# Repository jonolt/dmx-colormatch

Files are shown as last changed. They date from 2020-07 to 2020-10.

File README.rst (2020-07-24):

DMX-Colormatch
==============

The purpose of this project is to match the colors of color LED fixtures from different manufacturers and output the corresponding dmx values for further use in light control panels.

Especially for low cost LED fixtures often no photometric data is available, which can be imported into professional lighting control consoles to generate exact colors. With small light control consoles this is not possible by design. Especially for low cost LED fixtures often no photometric data is available, which can be imported into professional lighting control consoles to generate exact colors. With small light control consoles this is not possible by design. This leads to the situation that colours have to be adjusted manually with a lot of patience, which is still possible in the HSV colour space (available on mid-range consoles) but is hardly possible in pure RGB or with pure DMX values even for an experienced lighting technician.

Firmaware
---------

Approach
^^^^^^^^

A simple rgbc color sensor is used to record the characteristics of a color setting which is then matched by an algorithm on another fixture by systematically varying DMX values. The system is designed to suppress systematic errors by e.g. differences between sensors (which do not need to be calibrated), the algorithm also eliminates influences from the measurement such as the integration time, which varies depending on the light intesistance.

The algorithm tries to minimize the following equation with n colors of the sensor and one clear value that can be the sum of the readings of all the sensors colors or the reading of a clear sensor:

.. math::
    x = \sum_{i=0}^n \left(\frac{cur_i}{cur_c}-\frac{ref_i}{ref_c}\right)^2\quad\text{with}\quad xxx_c=\sum_{i=0}^n xxx_i

Using relative values eleminates intesity, which would is a systemtical error when the intesity or measuring distance differs between reference and target fixture. With the given sensor with red(r), green(g), blue(b), clear(c) readings the equation is (writen out):

.. math::
    x = \left(\frac{cur_r}{cur_c}-\frac{ref_r}{ref_c}\right)^2+\left(\frac{cur_g}{cur_c}-\frac{ref_g}{ref_c}\right)^2+\left(\frac{cur_b}{cur_c}-\frac{ref_b}{ref_c}\right)^2

Algorithm
^^^^^^^^^

Since no intesity is left, one dmx channel has to be made a reference channel and has to be constant. The most robust aproach is to make a match with each channel being at a given level (mostly 255) and variying the other. The run with the smallest x value is then the best solution.

The Algorithm itself is then quite simple:
  Flowchart is in work

Hardware
--------

work in progress

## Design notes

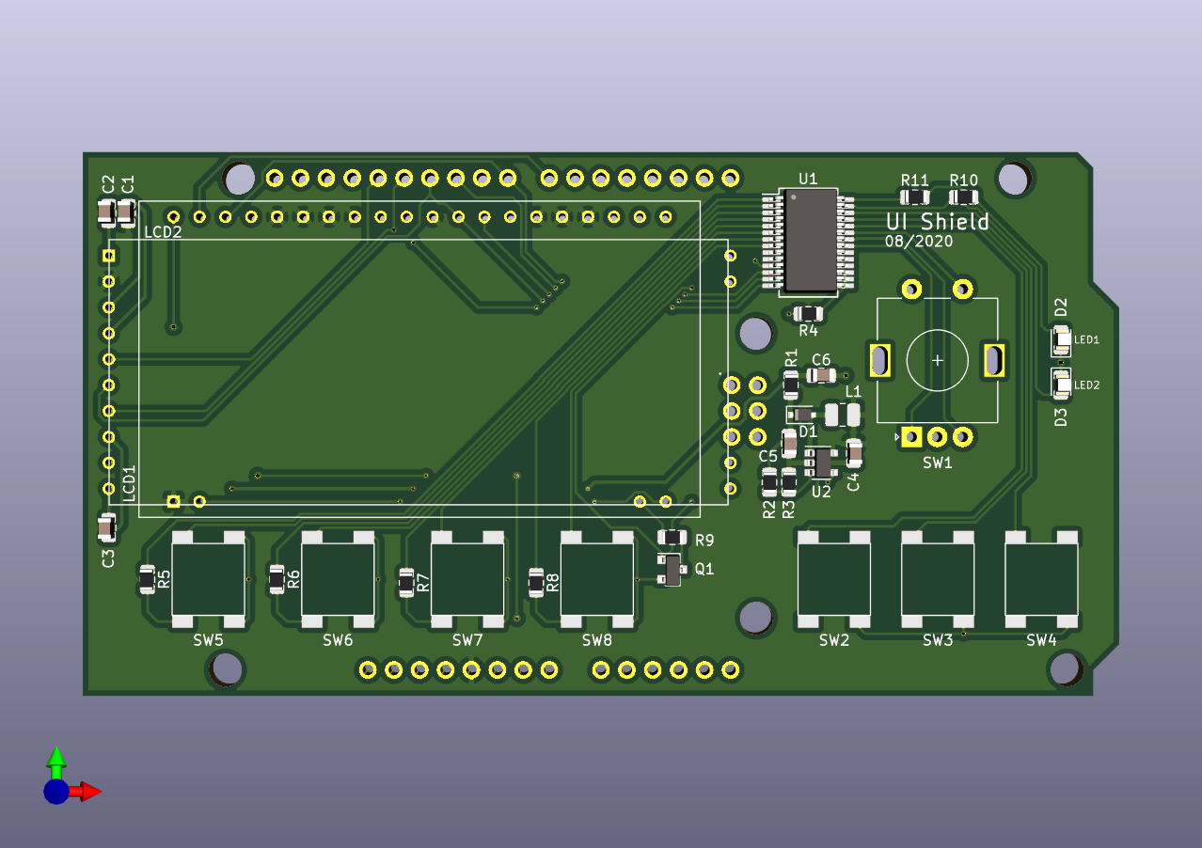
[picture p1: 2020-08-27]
board_kicad/UI-Shield/board_F.png

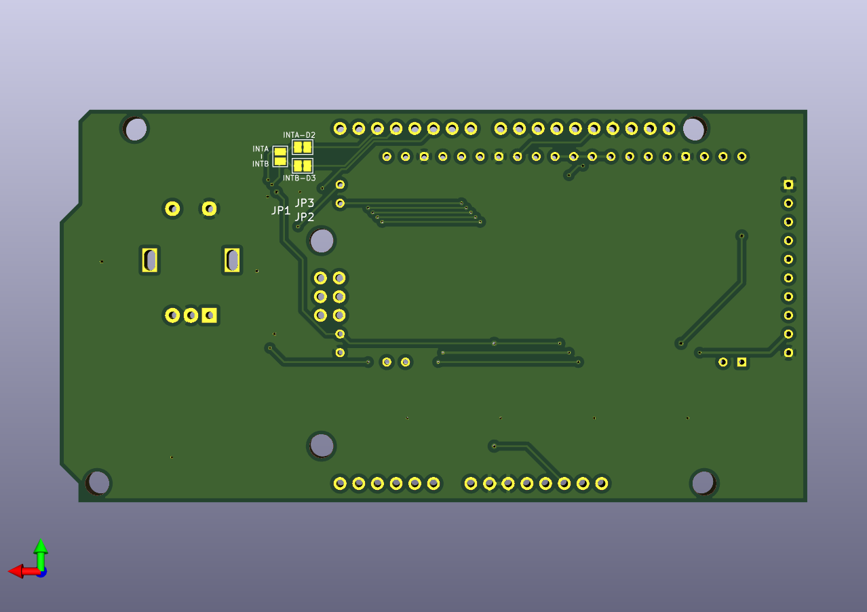
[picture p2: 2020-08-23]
board_kicad/UI-Shield/board_B.png

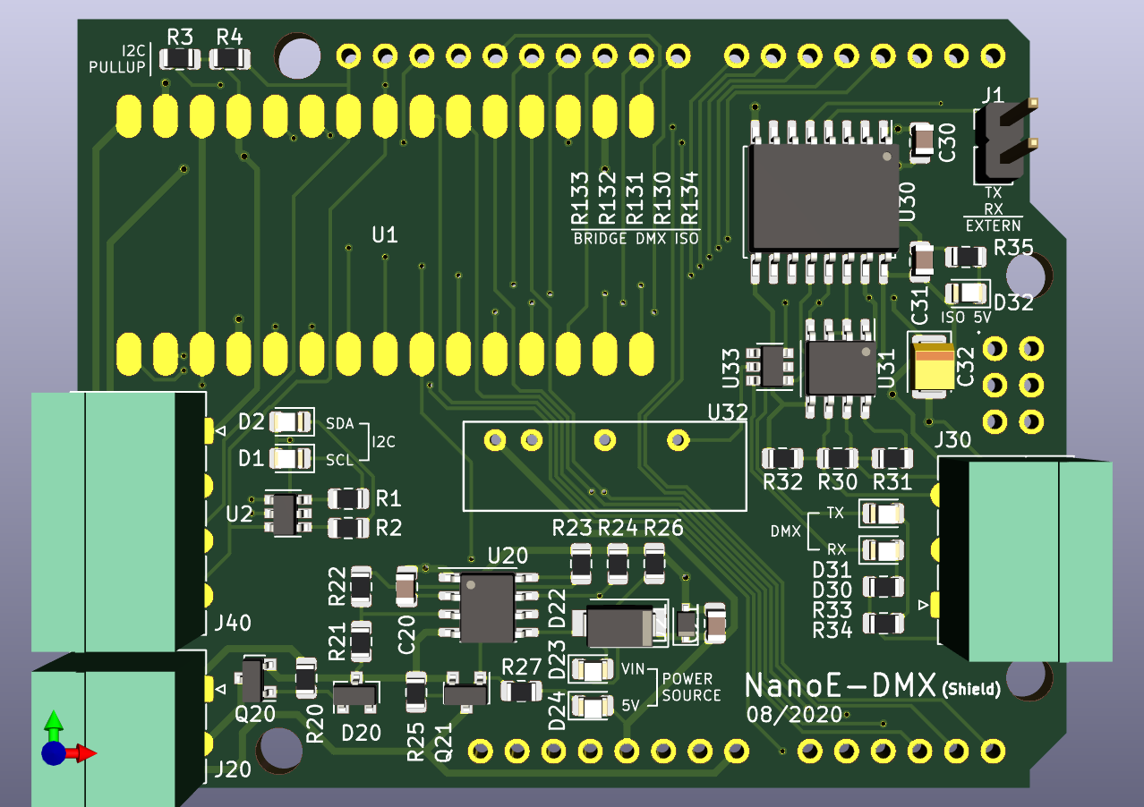
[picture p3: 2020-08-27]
board_kicad/NanoE-DMX/board_F.png

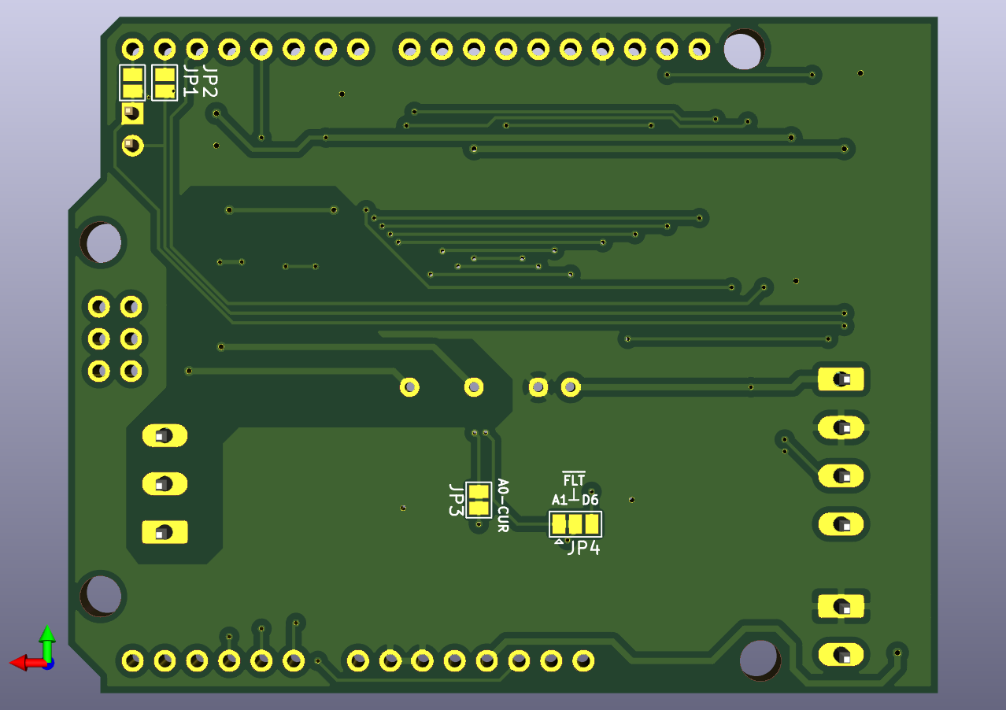
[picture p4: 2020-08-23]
board_kicad/NanoE-DMX/board_B.png

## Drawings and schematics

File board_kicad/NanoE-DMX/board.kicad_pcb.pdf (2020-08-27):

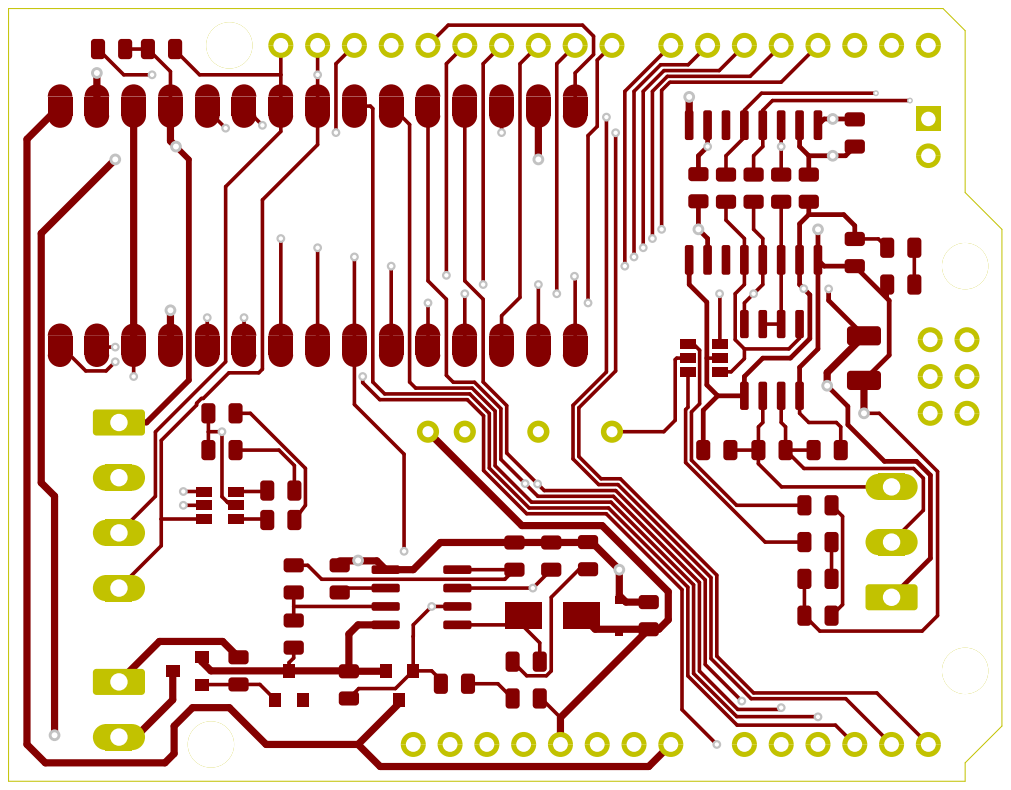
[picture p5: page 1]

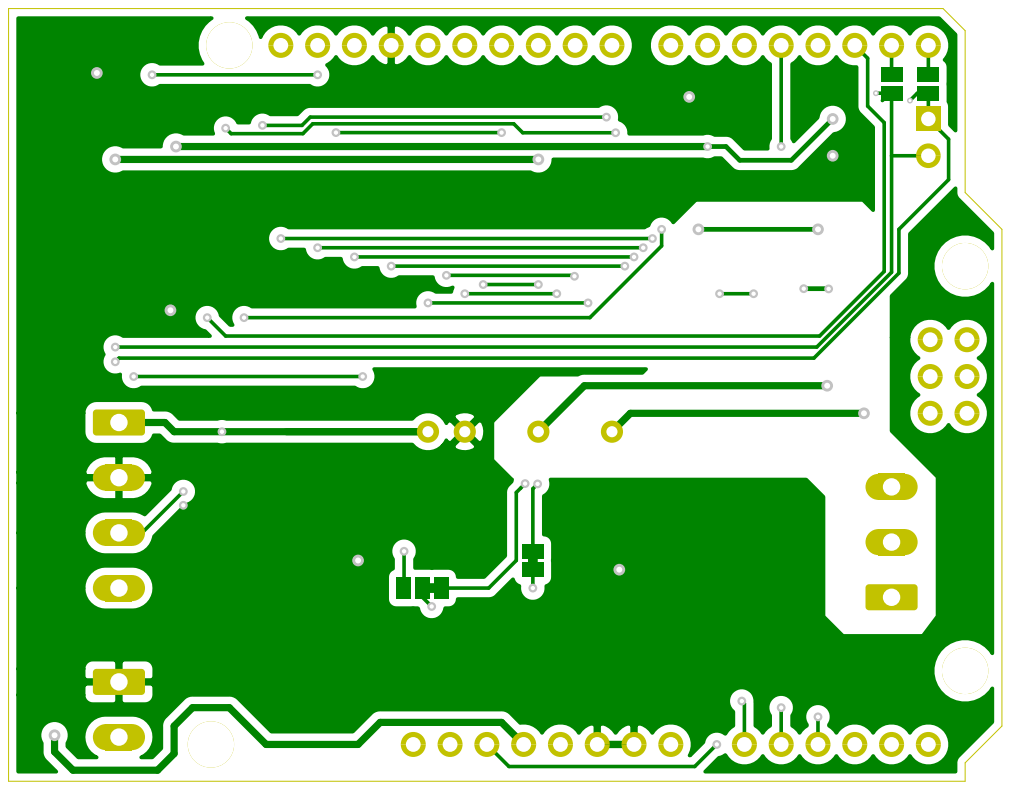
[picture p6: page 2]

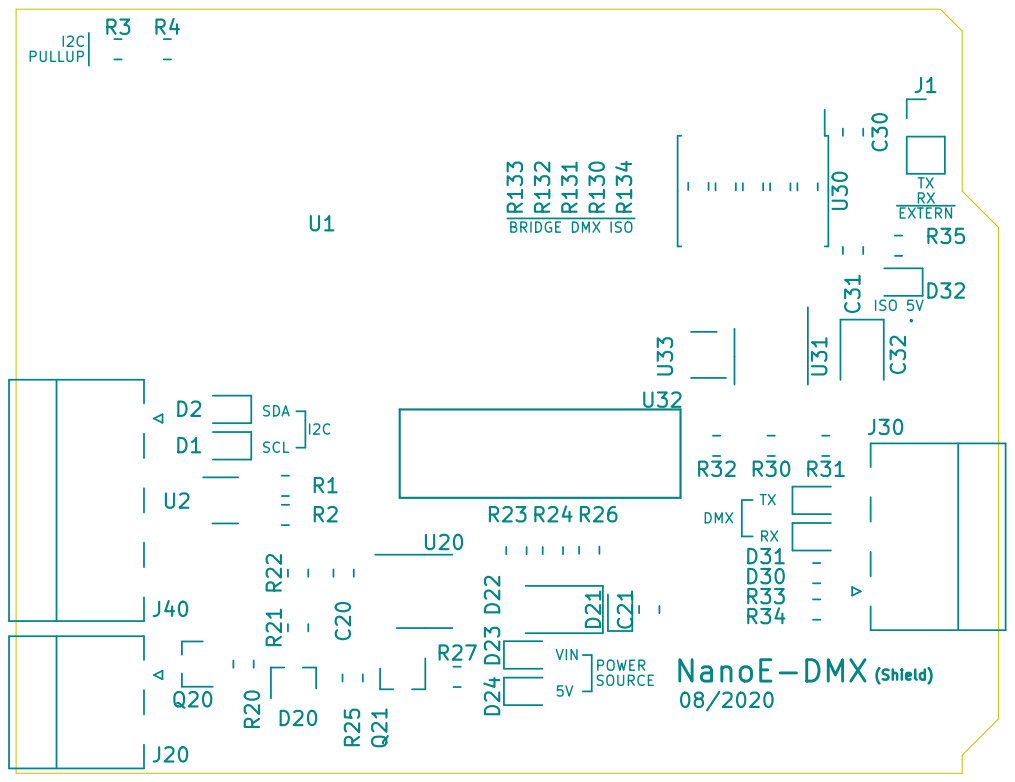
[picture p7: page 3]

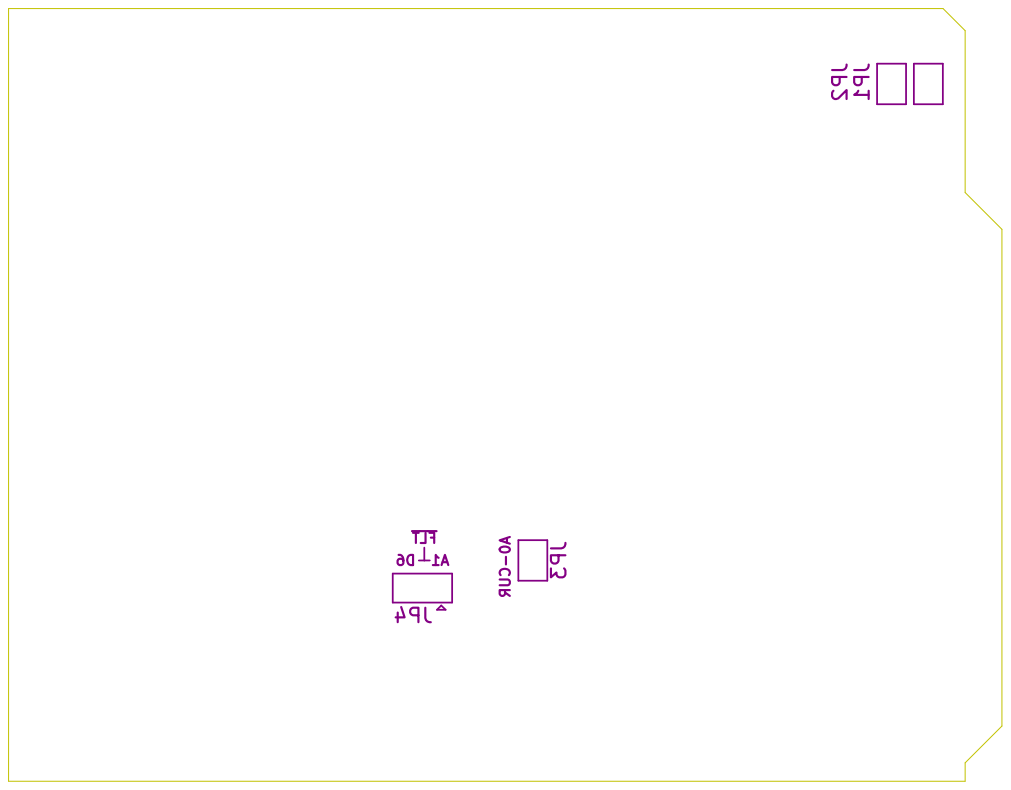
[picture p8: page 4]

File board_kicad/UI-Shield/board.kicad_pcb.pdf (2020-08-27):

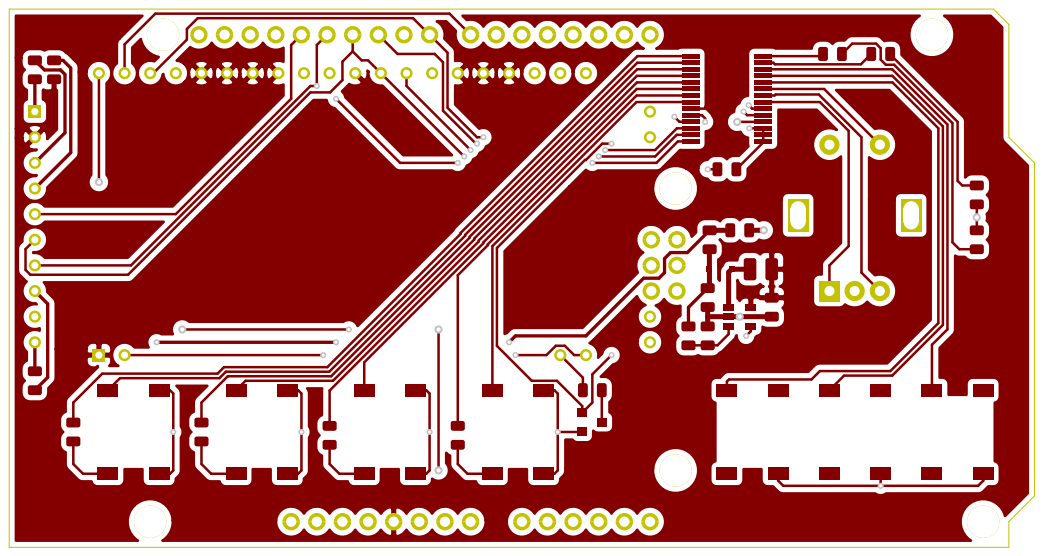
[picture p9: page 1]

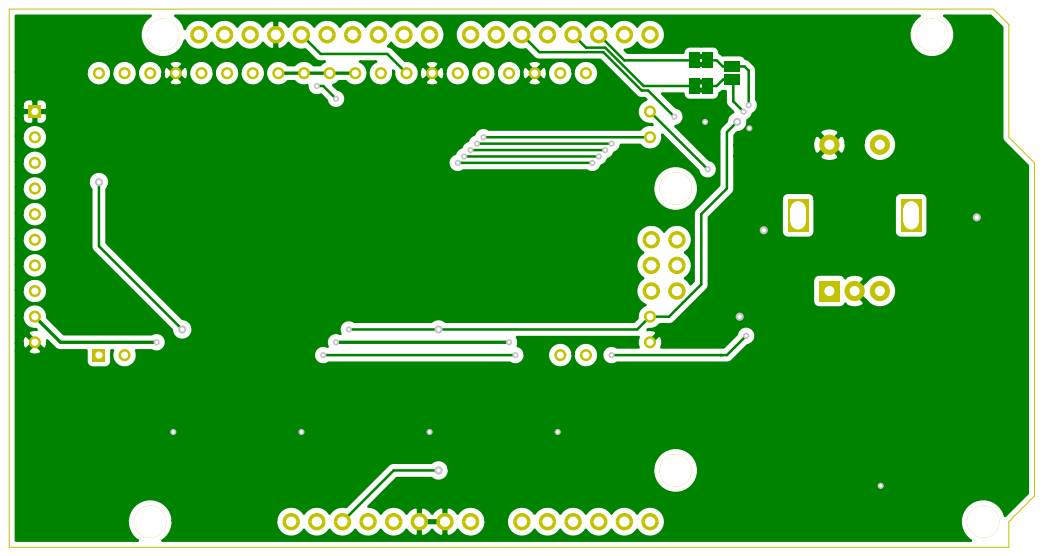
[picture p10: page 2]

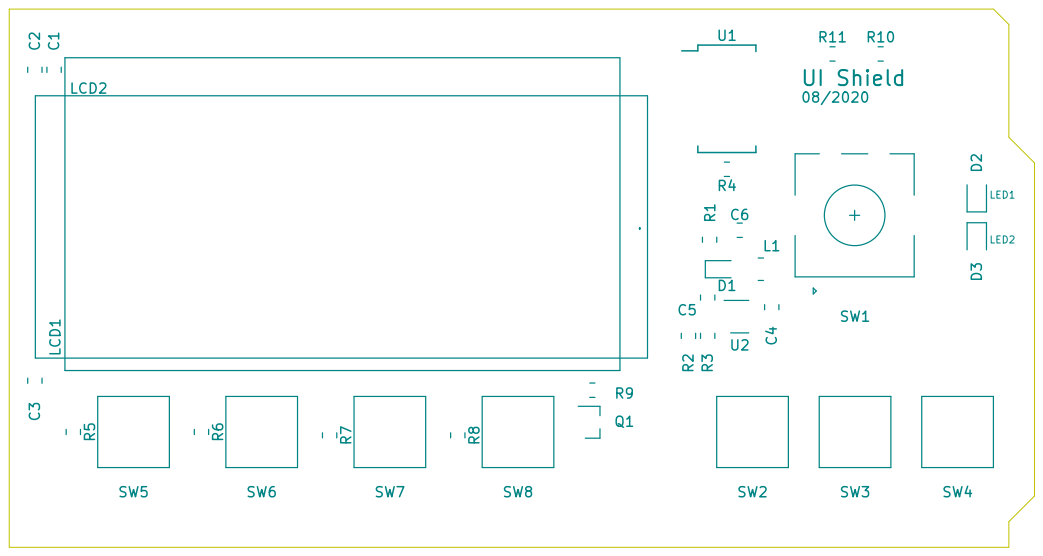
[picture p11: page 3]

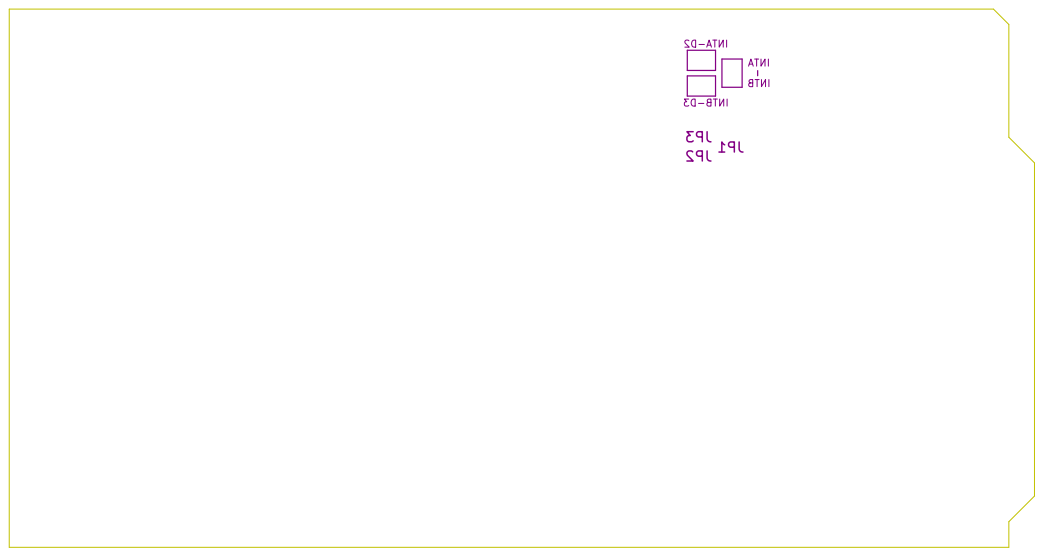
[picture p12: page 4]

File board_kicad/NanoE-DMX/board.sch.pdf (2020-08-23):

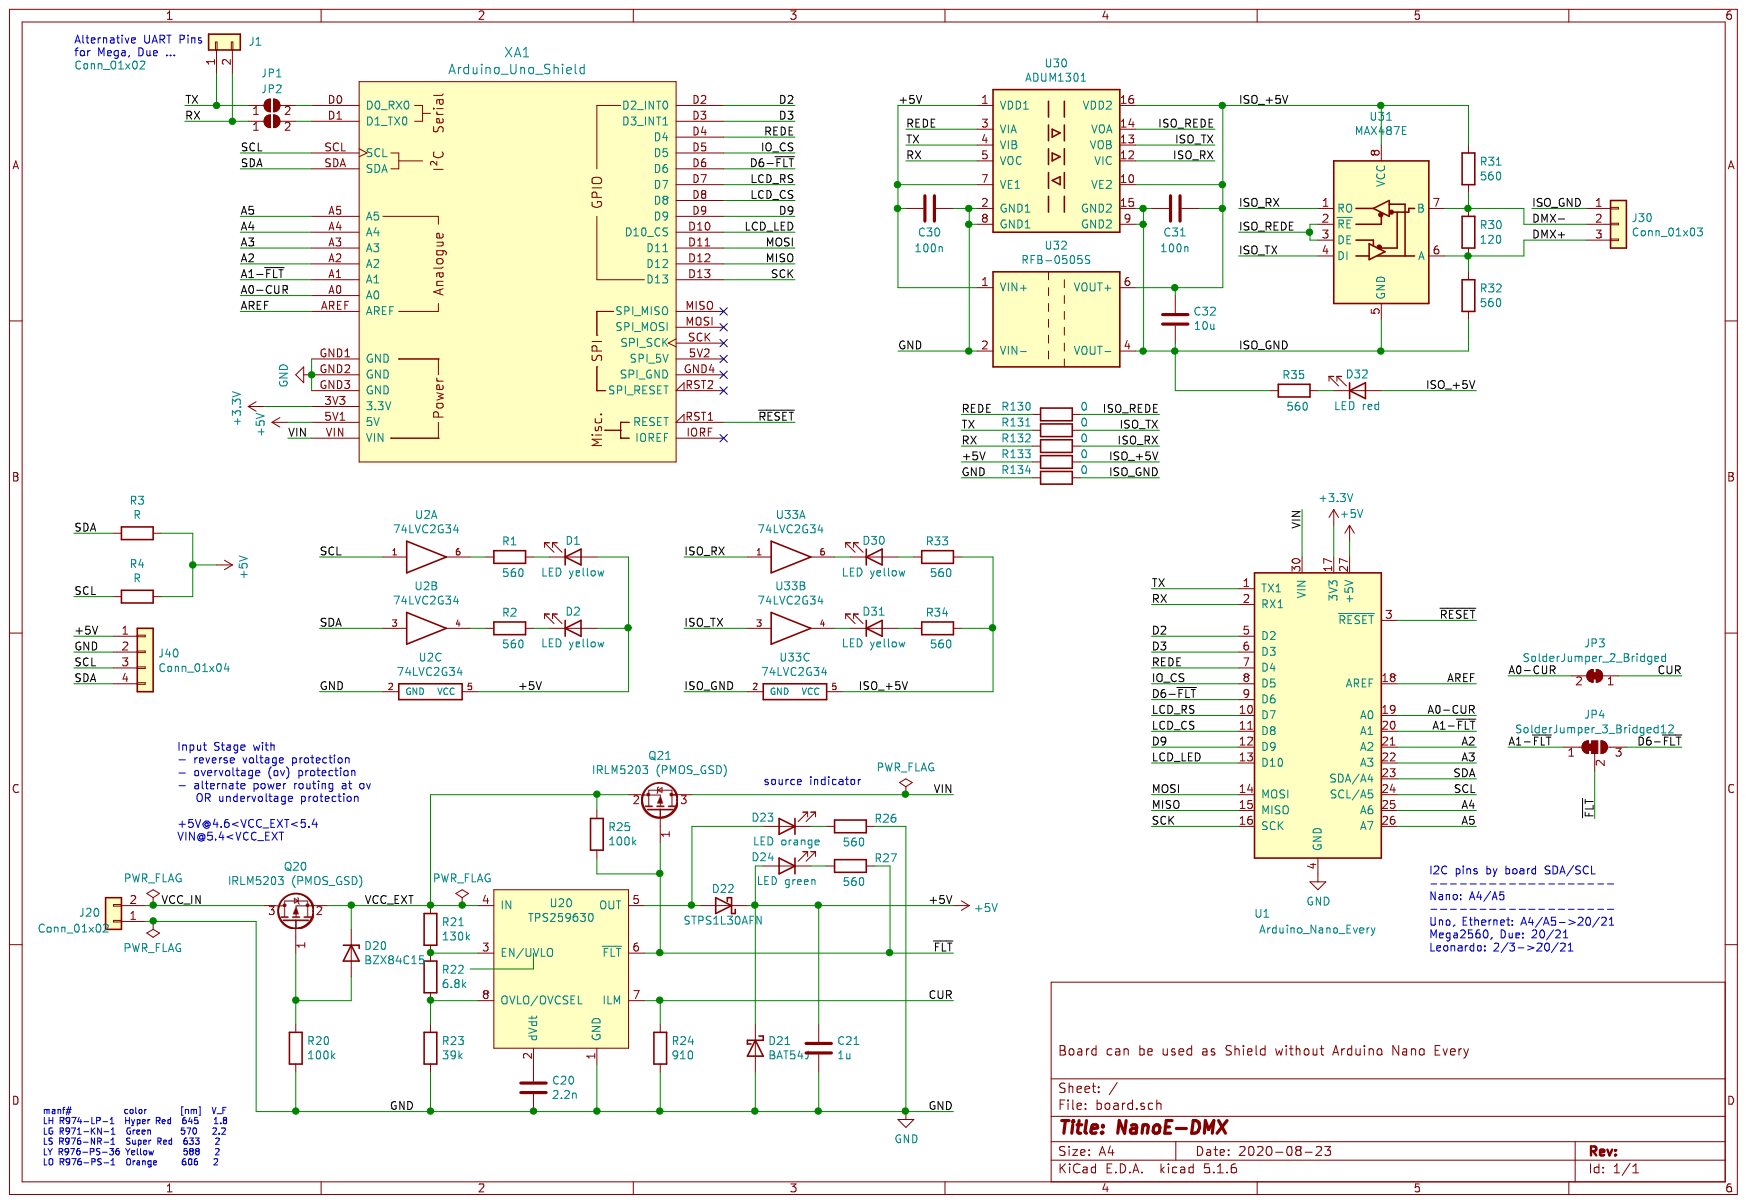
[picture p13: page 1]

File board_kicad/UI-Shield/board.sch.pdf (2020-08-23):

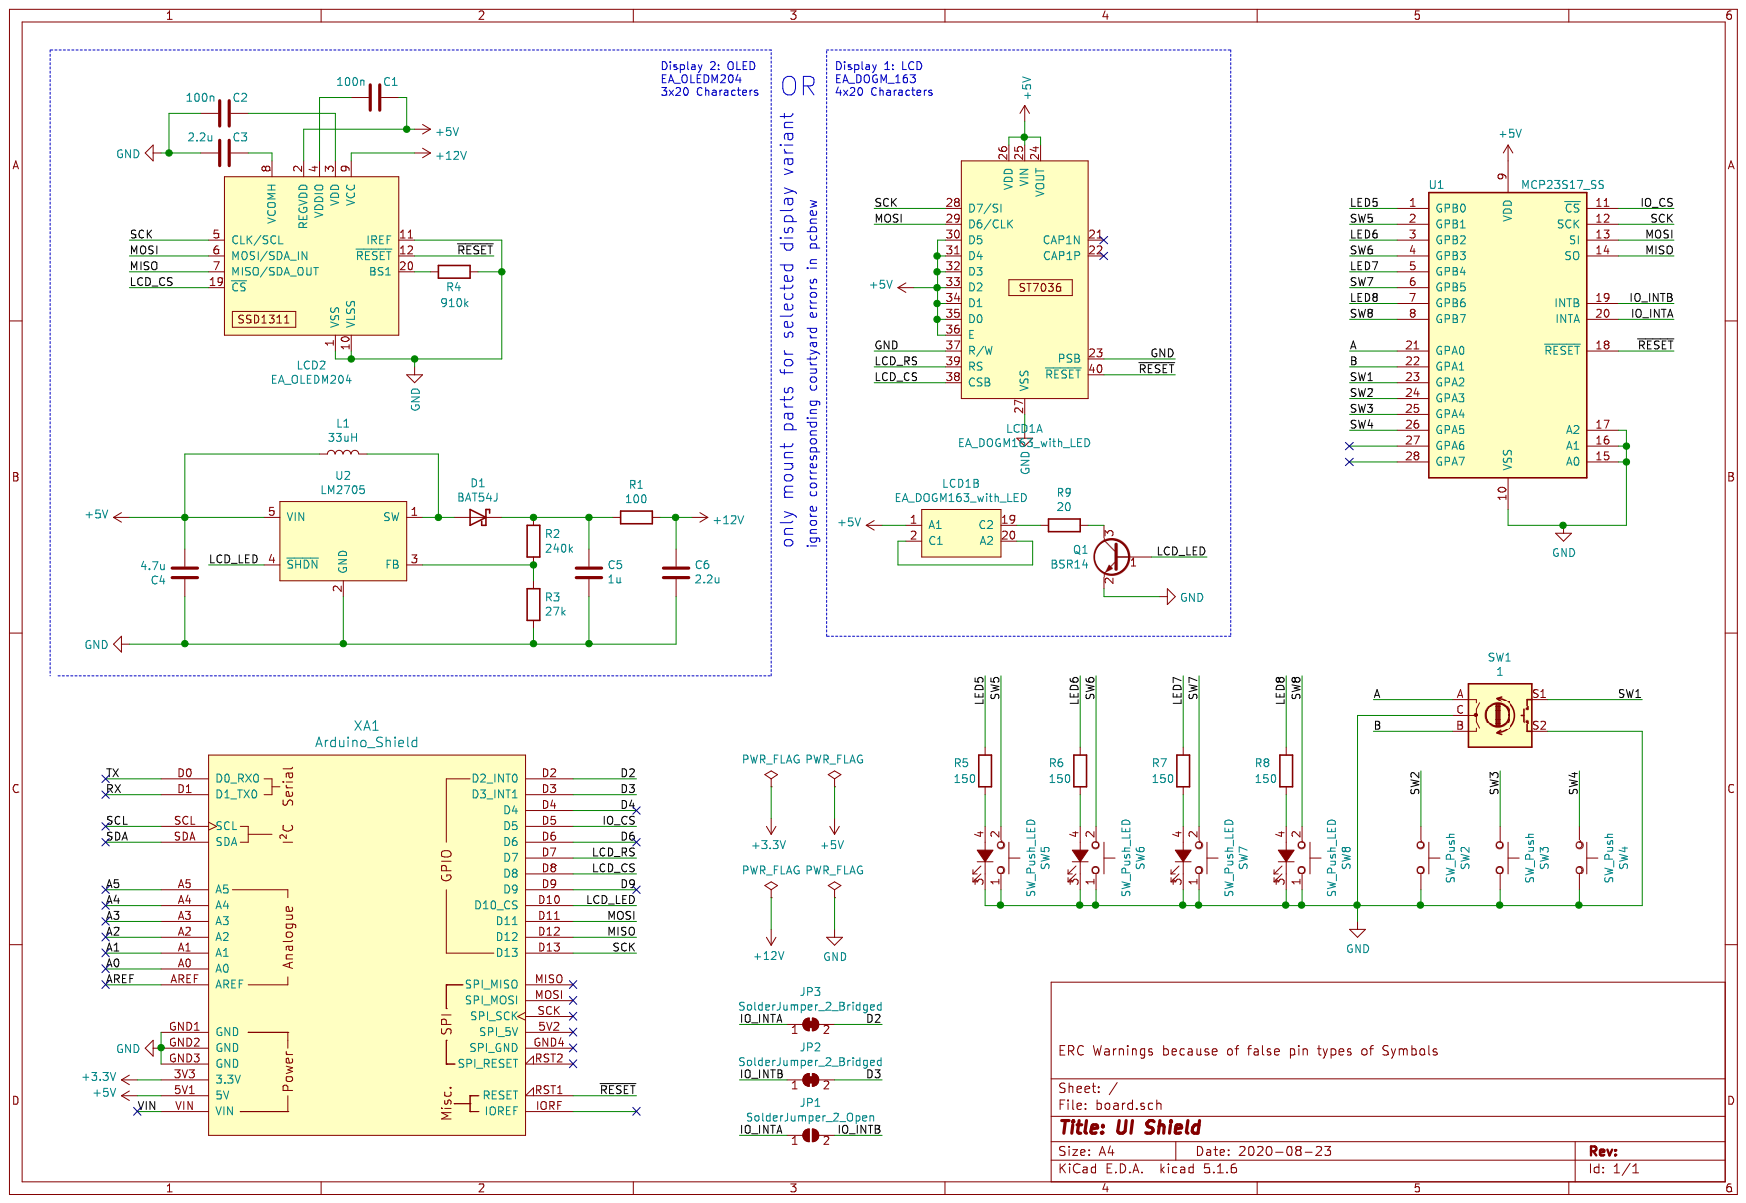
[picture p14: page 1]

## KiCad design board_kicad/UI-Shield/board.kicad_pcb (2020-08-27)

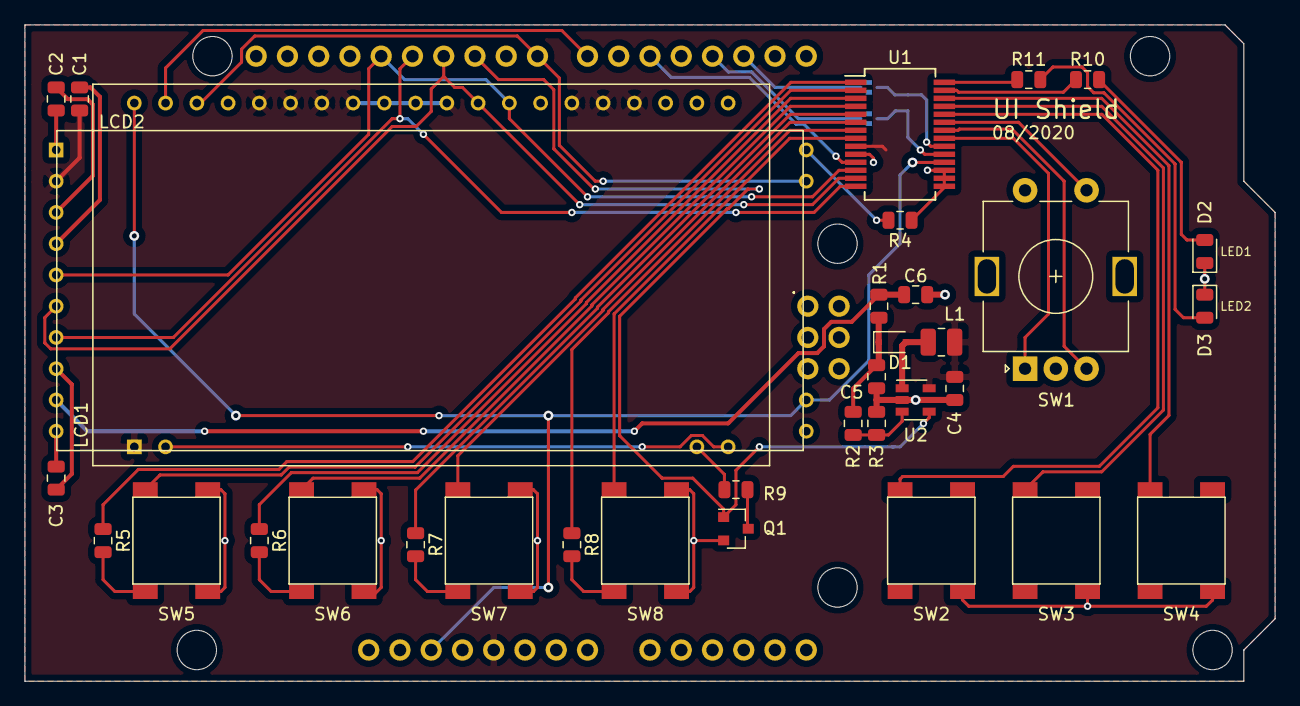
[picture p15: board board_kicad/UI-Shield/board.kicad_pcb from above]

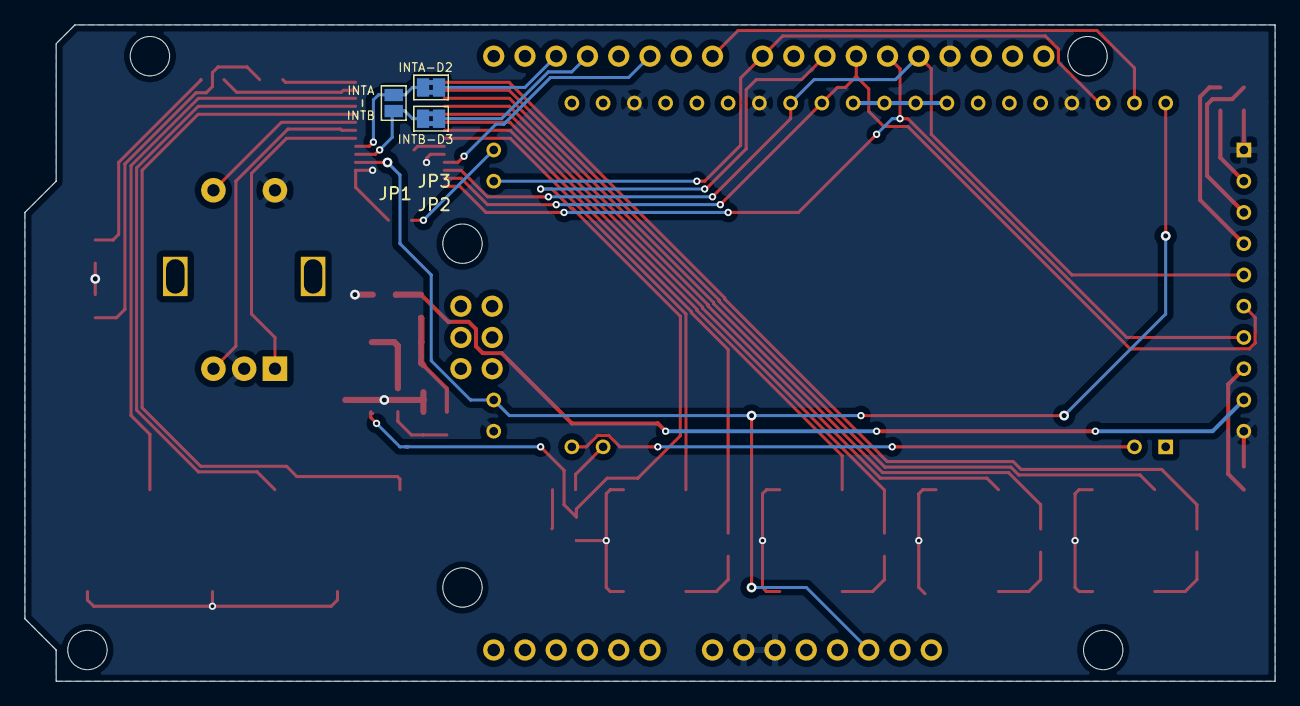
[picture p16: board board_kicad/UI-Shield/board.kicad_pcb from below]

Board: 2 copper layers, 101.6 x 53.3 mm, 38 parts (3 on the bottom side), 47 nets.

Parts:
C1, C2: 100n; C_0805_2012Metric
C3, C6: 2.2u; C_0805_2012Metric
C4: 4.7u; C_0805_2012Metric
C5: 1u; C_0805_2012Metric
D1: BAT54J; D_SOD-323F
D2, D3: LED; LED_0805_2012Metric
JP1: SolderJumper_2_Open; SolderJumper-2_P1.3mm_Open_Pad1.0x1.5mm
JP2, JP3: SolderJumper_2_Bridged; SolderJumper-2_P1.3mm_Bridged2Bar_Pad1.0x1.5mm
L1: 33uH; L_1008_2520Metric
LCD1: EA_DOGM163_with_LED; DOGM162_with_LED
LCD2: EA_OLEDM204; OLEDM204_6GGA
Q1: BSR14; SOT-23
R1: 100; R_0805_2012Metric
R2: 240k; R_0805_2012Metric
R3: 27k; R_0805_2012Metric
R4: 910k; R_0805_2012Metric
R5, R6, R7, R8: 150; R_0805_2012Metric
R9: 20; R_0805_2012Metric
R10, R11: 560; R_0805_2012Metric
SW1: 1; RotaryEncoder_Alps_EC11E-Switch_Vertical_H20mm
SW2, SW3, SW4: SW_Push; Marquardt_3006_Series
SW5, SW6, SW7, SW8: SW_Push_LED; Marquardt_3006_Series
U1: MCP23S17_SS; SSOP-28_5.3x10.2mm_P0.65mm
U2: LM2705; SOT-23-5
XA1: Arduino_Shield; Arduino_Shield_Large

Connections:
+5V: C1.1, C4.1, L1.1, LCD1.1, LCD1.24, LCD1.25, LCD1.26, LCD1.30, LCD1.31, LCD1.32, LCD1.33, LCD1.34, LCD1.35, LCD1.36, LCD2.2, U1.9, U2.5, XA1.5V1
+12V: C6.2, LCD2.9, R1.1
/A: SW1.A, U1.21
/B: SW1.B, U1.22
/D2: JP3.2, XA1.D2
/D3: JP2.2, XA1.D3
/IO_CS: U1.11, XA1.D5
/IO_INTA: JP1.1, JP3.1, U1.20
/IO_INTB: JP1.2, JP2.1, U1.19
/LCD_CS: LCD1.38, LCD2.19, XA1.D8
/LCD_LED: Q1.1, U2.4, XA1.D10
/LCD_RS: LCD1.39, XA1.D7
/LED1: R10.1, U1.27
/LED2: R11.1, U1.28
/LED5: R5.1, U1.1
/LED6: R6.1, U1.3
/LED7: R7.1, U1.5
/LED8: R8.1, U1.7
/MISO: LCD2.7, U1.14, XA1.D12
/MOSI: LCD1.29, LCD2.6, U1.13, XA1.D11
/SCK: LCD1.28, LCD2.5, U1.12, XA1.D13
/SW1: SW1.S1, U1.23
/SW2: SW2.2, U1.24
/SW3: SW3.2, U1.25
/SW4: SW4.2, U1.26
/SW5: SW5.2, U1.2
/SW6: SW6.2, U1.4
/SW7: SW7.2, U1.6
/SW8: SW8.2, U1.8
/~RESET: LCD1.40, LCD2.12, U1.18, XA1.RST1
GND: C2.2, C3.2, C4.2, C5.1, C6.1, D2.1, D3.1, LCD1.23, LCD1.27, LCD1.37, LCD2.1, LCD2.10, LCD2.11, Q1.2, R3.2, R4.1, SW1.C, SW1.S2, SW2.1, SW3.1, SW4.1, SW5.1, SW5.3, SW6.1, SW6.3, SW7.1, SW7.3, SW8.1, SW8.3, U1.10, U1.15, U1.16, U1.17, U2.2, XA1.GND1, XA1.GND2, XA1.GND3
unnamed: C1.2, LCD2.4
unnamed: C2.1, LCD2.3
unnamed: C3.1, LCD2.8
unnamed: C5.2, D1.1, R1.2, R2.1
unnamed: D1.2, L1.2, U2.1
unnamed: D2.2, R10.2
unnamed: D3.2, R11.2
unnamed: LCD1.2, LCD1.20
unnamed: LCD1.19, R9.2
unnamed: LCD2.20, R4.2
unnamed: Q1.3, R9.1
unnamed: R2.2, R3.1, U2.3
unnamed: R5.2, SW5.4
unnamed: R6.2, SW6.4
unnamed: R7.2, SW7.4
unnamed: R8.2, SW8.4

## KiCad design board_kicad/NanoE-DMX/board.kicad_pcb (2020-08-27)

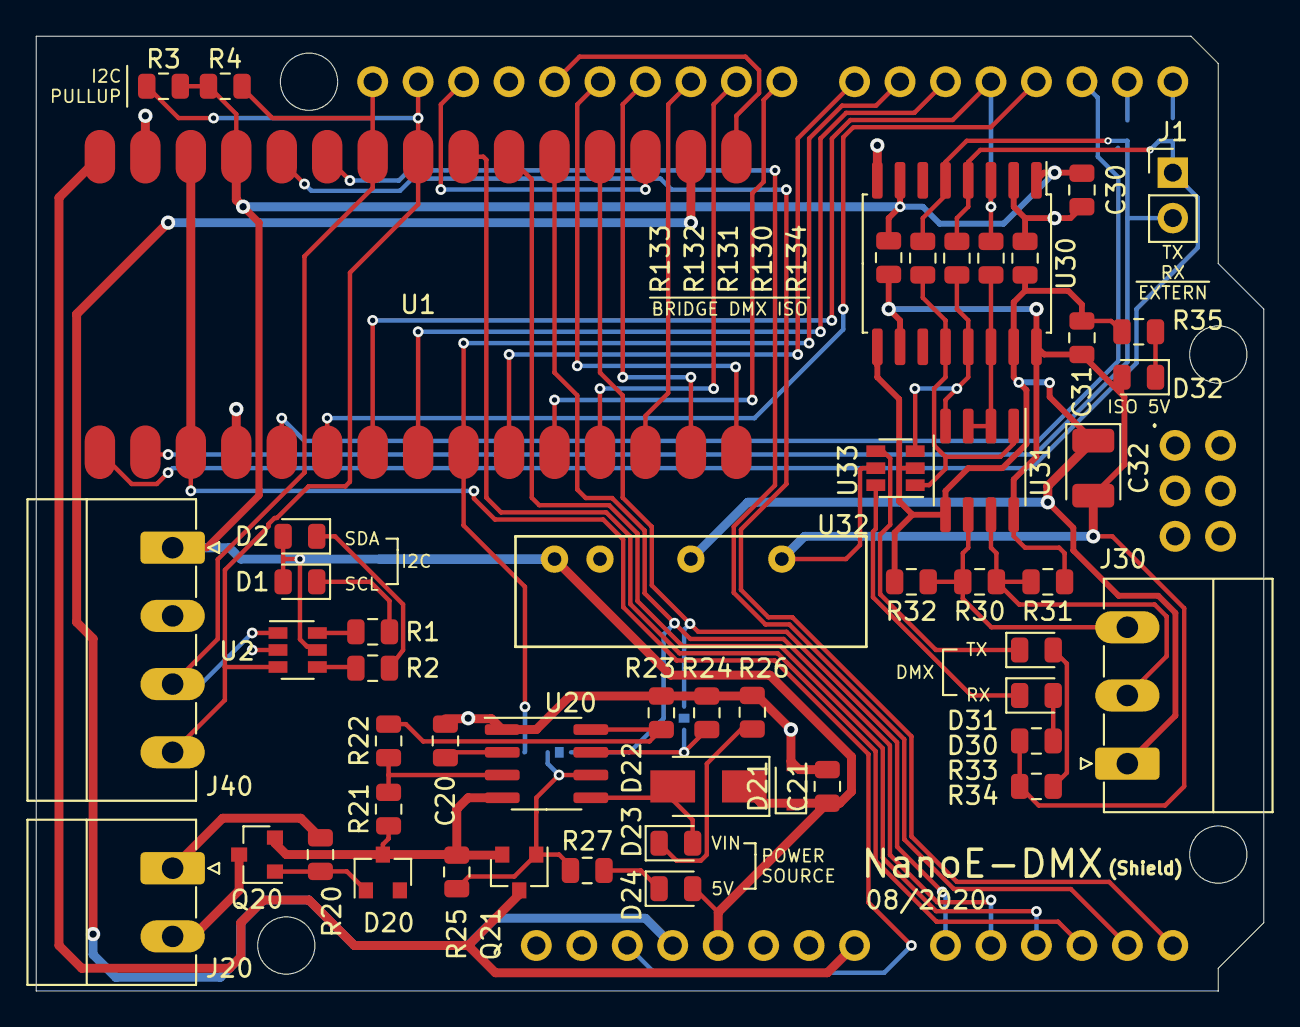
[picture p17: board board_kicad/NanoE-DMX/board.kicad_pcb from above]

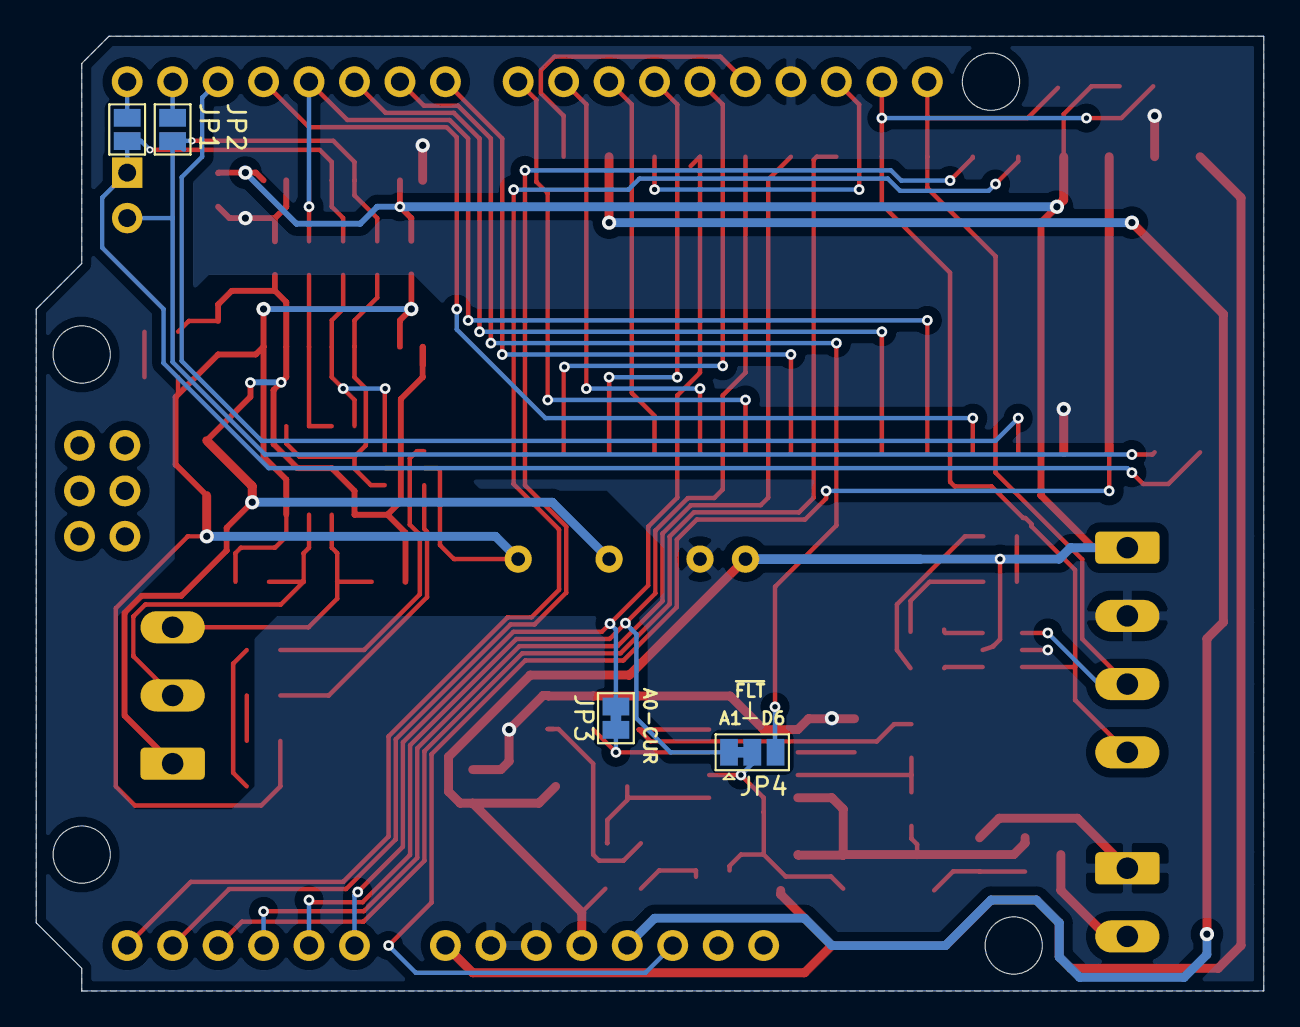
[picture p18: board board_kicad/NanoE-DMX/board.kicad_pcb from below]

Board: 2 copper layers, 68.6 x 53.3 mm, 56 parts (4 on the bottom side), 57 nets.

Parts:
C20: 2.2n; C_0805_2012Metric
C21: 1u; C_0805_2012Metric
C30, C31: 100n; C_0805_2012Metric
C32: 10u; CP_EIA-3528-15_AVX-H
D1, D2, D30, D31: LED yellow; LED_0805_2012Metric
D20: BZX84C15; D_SOT-23_ANK
D21: BAT54J; D_SOD-323F
D22: STPS1L30AFN; D_SMA
D23: LED orange; LED_0805_2012Metric
D24: LED green; LED_0805_2012Metric
D32: LED red; LED_0805_2012Metric
J1: Conn_01x02; PinHeader_1x02_P2.54mm_Vertical
J20: Conn_01x02; PhoenixContact_MC_1,5_2-G-3.81_1x02_P3.81mm_Horizontal
J30: Conn_01x03; PhoenixContact_MC_1,5_3-G-3.81_1x03_P3.81mm_Horizontal
J40: Conn_01x04; PhoenixContact_MC_1,5_4-G-3.81_1x04_P3.81mm_Horizontal
JP1, JP2: SolderJumper_2_Open; SolderJumper-2_P1.3mm_Open_Pad1.0x1.5mm
JP3: SolderJumper_2_Bridged; SolderJumper-2_P1.3mm_Bridged_Pad1.0x1.5mm
JP4: SolderJumper_3_Bridged12; SolderJumper-3_P1.3mm_Bridged12_Pad1.0x1.5mm
Q20, Q21: IRLM5203 (PMOS_GSD); SOT-23
R1, R2, R26, R27, R31, R32, R33, R34, R35: 560; R_0805_2012Metric
R3, R4: R; R_0805_2012Metric
R20, R25: 100k; R_0805_2012Metric
R21: 130k; R_0805_2012Metric
R22: 6.8k; R_0805_2012Metric
R23: 39k; R_0805_2012Metric
R24: 910; R_0805_2012Metric
R30: 120; R_0805_2012Metric
R130, R131, R132, R133, R134: 0; R_0805_2012Metric
U1: Arduino_Nano_Every; Nano_Every_SMD
U2, U33: 74LVC2G34; SOT-23-6
U20: TPS259630; SOIC-8_3.9x4.9mm_P1.27mm
U30: ADUM1301; SOIC-16W_7.5x10.3mm_P1.27mm
U31: MAX487E; SOIC-8_3.9x4.9mm_P1.27mm
U32: RFB-0505S; SIP7-1-2-4-6
XA1: Arduino_Uno_Shield; Arduino_Shield

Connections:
+3V3: U1.17, XA1.3V3
+5V: C21.1, C30.2, D1.2, D2.2, D21.1, D22.1, D24.2, J40.1, R3.1, R4.1, R133.2, U1.27, U2.5, U30.1, U30.7, U32.1, XA1.5V1
/A0-CUR: JP3.2, U1.19, XA1.A0
/A1-~FLT: JP4.1, U1.20, XA1.A1
/A2: U1.21, XA1.A2
/A3: U1.22, XA1.A3
/A4: U1.25, XA1.A4
/A5: U1.26, XA1.A5
/AREF: U1.18, XA1.AREF
/CUR: JP3.1, R24.1, U20.7
/D2: U1.5, XA1.D2
/D3: U1.6, XA1.D3
/D6-~FLT: JP4.3, U1.9, XA1.D6
/D9: U1.12, XA1.D9
/DMX+: J30.3, R30.2, R32.1, U31.6
/DMX-: J30.2, R30.1, R31.2, U31.7
/IO_CS: U1.8, XA1.D5
/ISO_+5V: C31.1, C32.2, D32.2, R31.1, R33.1, R34.1, R133.1, U30.10, U30.16, U31.8, U32.6, U33.5
/ISO_GND: C31.2, C32.1, J30.1, R32.2, R35.2, R134.1, U30.9, U30.15, U31.5, U32.4, U33.2
/ISO_REDE: R130.1, U30.14, U31.2, U31.3
/ISO_RX: R132.1, U30.12, U31.1, U33.1
/ISO_TX: R131.1, U30.13, U31.4, U33.3
/LCD_CS: U1.11, XA1.D8
/LCD_LED: U1.13, XA1.D10
/LCD_RS: U1.10, XA1.D7
/MISO: U1.15, XA1.D12
/MOSI: U1.14, XA1.D11
/REDE: R130.2, U1.7, U30.3, XA1.D4
/RX: J1.2, JP2.1, R132.2, U1.2, U30.5
/SCK: U1.16, XA1.D13
/SCL: J40.3, R4.2, U1.24, U2.1, XA1.SCL
/SDA: J40.4, R3.2, U1.23, U2.3, XA1.SDA
/TX: J1.1, JP1.1, R131.2, U1.1, U30.4
/VCC_EXT: D20.1, Q20.2, Q21.2, R21.1, R25.1, U20.4
/VCC_IN: J20.2, Q20.3
/VIN: Q21.3, U1.30, XA1.VIN
/~FLT: JP4.2, Q21.1, R25.2, R27.1, U20.6
/~RESET: U1.3, U1.28, XA1.RST1
GND: C20.2, C21.2, C30.1, D21.2, J20.1, J40.2, R20.2, R23.2, R24.2, R26.1, R134.2, U1.4, U1.29, U2.2, U20.1, U30.2, U30.8, U32.2, XA1.GND1, XA1.GND2, XA1.GND3
unnamed: C20.1, U20.2
unnamed: D1.1, R1.1
unnamed: D2.1, R2.1
unnamed: D20.2, Q20.1, R20.1
unnamed: D22.2, D23.2, U20.5
unnamed: D23.1, R26.2
unnamed: D24.1, R27.2
unnamed: D30.1, U33.6
unnamed: D30.2, R33.2
unnamed: D31.1, U33.4
unnamed: D31.2, R34.2
unnamed: D32.1, R35.1
unnamed: JP1.2, XA1.D0
unnamed: JP2.2, XA1.D1
unnamed: R1.2, U2.6
unnamed: R2.2, U2.4
unnamed: R21.2, R22.1, U20.3
unnamed: R22.2, R23.1, U20.8

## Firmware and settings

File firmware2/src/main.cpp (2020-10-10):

#include <Arduino.h>
#include <SPI.h>

#include <DMXSerial.h>
#include "TCS34725.h"

#include "globals.h"
#include "serial.h"

#include "fsmmain.h"
#include "parandvals.h"

#include "fsmui.h"
#include "AtmButtonExp.h"

#define SPLIT_CHAR ' '

void(* resetFunc) (void) = 0;

void print(String str)
{
    uint8_t bufferLeft = Serial.availableForWrite();
    if(str.length() < bufferLeft)
    {
        Serial.print(str);
    }
}

template <typename T>
String formatValues(T val, const char* formatter)
{
    char buff[SPRINTF_BUFFER_SIZE];
    sprintf(buff, formatter, val);
    return String(buff);
}

template <typename T>
String param_print_values(T _array[], int _size, const char* formatter)
{
    char buff[SPRINTF_BUFFER_SIZE];
    String str_print = "";
    for (int i = 0; i < _size; i++)
    {
        if(i>0 && i<_size)
        {
            str_print += SPLIT_CHAR;
        }
        sprintf(buff, formatter, _array[i]);
        str_print += String(buff);
    }
    return str_print;
}


template <typename T>
uint8_t array_from_string(T target[], String str, uint8_t charsInVal, uint8_t _size)
{
#ifdef _DEBUG
    print("parsing string: " + str + " with " + String(_size) + " argumnets\n");
#endif // _DEBUG
    uint8_t arr_index=0;
    for(unsigned int i = 0; i<str.length(); i++)
    {
        if(str[i]==SPLIT_CHAR)
        {
            String sub_str = str.substring(i+1, i+1+charsInVal);
            //print("arr_index: " + String(arr_index) + "-" + sub_str + "\n");
            target[arr_index] = sub_str.toInt();
            //print("as int: " + String(target[arr_index]) + "\n");
            arr_index++;
            if(arr_index==_size)
            {
                return 0;
            };
            //delay(1);
        }
    }
    return 2;
}

//TODO algorithm to detect reaction time of dmx fixtures
//TODO set boudrate via serial and save in EEPROM

FsmMain fsm_main;
FsmUi fsm_ui;
ParAndVals pav;
AtmButtonExp buttons[8];
Atm_led leds[8];
TCS34725 csensor;

uint16_t tmpRGBC[NUM_SENSOR_VALUES];
uint8_t tmpDMX[NUM_COLOR_CHANNELS];

//inline void initButtons()
//{
//    for (uint8_t i = 0; i<sizeof(BUTTON_MAP); i++)
//    {
////        buttons[i].begin( BUTTON_MAP[i] ).onPress(fsm_ui, i);
//    }
//}
//
//inline void cycleButtons()
//{
//    for (AtmButtonExp sw : buttons)
//    {
////        sw.cycle();
//    }
//}
//
//inline void initLEDs()
//{
//    for (uint8_t i = 0; i<sizeof(LED_MAP); i++)
//    {
//
//    }
//}
//
//inline void cycleLEDs()
//{
//    for (Atm_led d : leds)
//    {
////        d.cycle();
//    }
//}

inline void initSerial()
{
    Serial.begin( 115200 );
    if(pav.GetWaitForSerialFlag()==true)
    {
        //check if SDA and SCL a shortened, if yeas act as waitForSerialFlag is clear
        //wait for any serial input to start;
        while(Serial.available() == 0);
        // then clear the buffer
        while(Serial.available() > 0)
        {
            Serial.read();
        }
        print("~WaitForSerialFlag cleared.\n");
        pav.SetWaitForSerialFlag(false);
    }
}

void updateDmx(uint8_t dmx[])
{
    for(uint8_t i = 0; i<pav.GetcolorChanels(); i++)
    {
        //print("dmx write ch '" + String(pav.GetstartAddress()+i) + "' to value '" + formatValues(dmx[i], F_DMX) + "'\n");
        DMXSerial.write(pav.GetstartAddress()+i, dmx[i]);
        delay(2);
    }
    print("~DMX " + param_print_values(dmx, pav.GetcolorChanels(), F_DMX) + "\n");
}

void readDmx(uint8_t dmx[])
{
    for(uint8_t i = 0; i<pav.GetcolorChanels(); i++)
    {
        dmx[i] = DMXSerial.read(pav.GetstartAddress()+i);
    }
}

inline void readSerial()
{
    String error_msg;
    if(Serial.available()>0)
    {
        String str = Serial.readStringUntil('\n');
        str.trim();
        // reset microcontoller
        if(str.equals("RESET"))
        {
            print(">resetting ...\n");
            Serial.flush();
            resetFunc();
            return;
        }
        // set wait for serial flag
        else if(str.equals("WFS") || str.equals("wait for serial, please"))
        {
            print("~WaitForSerialFlag set.\n");
            pav.SetWaitForSerialFlag(true);
            return;
        }
        //set value of address channel (Syntax: DMX ADD VAL)
        else if(str.startsWith("DMX#"))
        {
            uint8_t add = str.substring(5,8).toInt();
            if (add>=DMX_ADD_MIN && add<=DMX_ADD_MAX)
            {
                uint8_t val = str.substring(9,12).toInt();
                if(val>=DMX_VAL_MIN && val<=DMX_VAL_MAX)
                {
                    DMXSerial.write(add, val);
                    print("#DMX address '" + formatValues(add, F_DMX) + "' set to '" + formatValues(val, F_VAL) + "'\n" );
                    return;
                }
                error_msg = "value '" + str.substring(5,8) + "' is not a channel valid number (001-255)";
            }
            error_msg = "value '" + str.substring(9,12) + "' is not a channel valid number (000-254)";
        }
        else if(str.startsWith("DMX&"))
        {
            // TODO check input is valid
            int8_t ch = str.substring(5,8).toInt();
            int16_t add = pav.GetstartAddress() + ch - 1;
            if (add>=DMX_ADD_MIN && ch<=DMX_ADD_MAX)
            {

                uint8_t val = str.substring(9,12).toInt();
                if(val>=DMX_VAL_MIN && val<=DMX_VAL_MAX)
                {
                    DMXSerial.write(add, val);
                    print("&DMX channel '" + formatValues(ch, F_DMX) + "' set to '" + formatValues(val, F_VAL) + "'\n" );
                    return;
                }
                error_msg = "value '" + str.substring(5,8) + "' is not a channel valid number (001-255)";
            }
            error_msg = "value '" + str.substring(9,12) + "' is not a channel valid number (000-254)";
        }
        //reset all channels to 0
        else if(str.startsWith("DMX*"))
        {
            for(int add=DMX_ADD_MIN; add<=DMX_ADD_MAX; add++)
            {
                DMXSerial.write(add, 0);
            }
            print("*DMX all channels set to 0\n");
            return;
        }
        // get current dmx output, ommiting 0 except color channels
        else if(str.startsWith("DMX?"))
        {
            print("?DMX (ADD/CH) VAL)\n");
            uint8_t dmx_lower = pav.GetstartAddress();
            uint8_t dmx_upper = dmx_lower + pav.GetcolorChanels();
            for(int add=DMX_ADD_MIN; add<=DMX_ADD_MAX; add++)
            {
                uint8_t val = DMXSerial.read(add);
                if(val>0 || (add>=dmx_lower && add<dmx_upper))
                {
                    print("  " + formatValues(add, F_DMX) + "/" + formatValues(add+dmx_lower-1, F_DMX) + " " + formatValues(val, F_VAL) + "\n");
                }
            }
            return;
        }
        // set dmx channels with cuurrent global setting (nuber of channels, start address)
        else if(str.startsWith("DMX"))
        {
            uint8_t dmx_vals[NUM_COLOR_CHANNELS];
            uint8_t arrayExitCode = array_from_string(dmx_vals, str.substring(3), 3, pav.GetcolorChanels());
            if(arrayExitCode==0)
            {
                print(">DMX " + param_print_values(dmx_vals, pav.GetcolorChanels(), F_DMX) + "\n");
                updateDmx(dmx_vals);
                return;
            }
            error_msg = "exit code " + String(arrayExitCode) + "parsing string: " + str;
        }
        //get number of color channels
        else if(str.startsWith("NCH?"))
        {
            print("?NCH " + formatValues(pav.GetcolorChanels(), F_CH) + "\n");
            return;
        }
        // set number of color channels
        else if(str.startsWith("NCH"))
        {
            uint8_t n_ch = str.substring(4).toInt();
            if (n_ch>0 && n_ch<=NUM_COLOR_CHANNELS)
            {
                pav.SetcolorChanels(n_ch);
                print(">NCH " + formatValues(pav.GetcolorChanels(), F_CH) + "\n");
                return;
            }
            error_msg = "value '" + str.substring(4) + "' is not a channel valid number (1-8)";
        }
        // get dmx start address
        else if(str.startsWith("ADD?"))
        {
            print("?ADD " + formatValues(pav.GetstartAddress(), F_DMX) + "\n");
            return;
        }
        // set dmx start address
        else if(str.startsWith("ADD"))
        {
            uint8_t add = str.substring(4, 7).toInt();
            if (add>=DMX_ADD_MIN && DMX_ADD_MAX<=255)
            {
                pav.SetstartAddress(add);
                print(">ADD " + formatValues(pav.GetstartAddress(), F_DMX) + "\n");
                return;
            }
            error_msg = "value '" + str.substring(4, 7) + "' is not a valid address number (001-255)";
        }
        // get active register
        else if(str.startsWith("REG?"))
        {
            print("?REG " + formatValues(pav.GetActiveRegister(), F_REG) + "\n");
            return;
        }
        // set active register
        else if(str.startsWith("REG"))
        {
            uint8_t reg = str.substring(4,6).toInt();
            if(reg>0 && reg<=NUM_REGISTER)
            {
                pav.SetActiveRegister(reg);
                print(">REG " + formatValues(pav.GetActiveRegister(), F_REG) + "\n");
                return;
            }
            error_msg = "value '" + str.substring(4,6) + "' is not a valid register number (01-16)";
        }
        // return register rgbc values of active register
        else if(str.equals("RRGBC?"))
        {
            pav.GetRegRgbc(tmpRGBC);
            print("?RRGBC " + param_print_values(tmpRGBC, NUM_SENSOR_VALUES, F_RGBC) + "\n");
            return;
        }
        // return register dmx values of active register
        else if(str.equals("RDMX?"))
        {
            pav.GetRegDmx(tmpDMX);
            print("?RDMX " + param_print_values(tmpDMX, pav.GetcolorChanels(), F_DMX) + "\n");
            return;
        }
        // send register dmx values to dmx output
        else if(str.equals("RDMX!"))
        {
            pav.GetRegDmx(tmpDMX);
            print("!RDMX " + param_print_values(tmpDMX, pav.GetcolorChanels(), F_DMX) + "\n");
            updateDmx(tmpDMX);
            return;
        }
//        else if (str.equals("REF"))
//        {
//
//        }
//        else if (str.equals("MATCH"))
//        {
//
//        }
        else
        {
            print("ERROR: invalid string: " + str + "\n");
            return;
        }
        print("ERROR: parsing string '" + str + "': " + error_msg + "\n");
    }
}

inline void initSensor()
{
    while (!csensor.begin())
    {
        print("No TCS34725 found ... check your connections\n");
        delay(1000);
    }
    print("Found sensor at I2C-Address " + String(csensor.getSensorAddress()) + "\n");
    csensor.setIntegrationTime(4.8);
}

void setup()
{
    //DO read wait for serial flag from EEPROM
    pav = ParAndVals();
    initSerial();

    print("DMXE; Version " + String(VERSION) + "\n");

    DMXSerial.init(DMXController, REDE);

    initSensor();
    //DO init expander
//    initButtons();
//    initLEDs();
    //DO init diplay
    fsm_main = FsmMain();
    //fsm_ui = FsmUi();
    print("setup done, continue to main loop\n");
}

inline void addToRGBSum()
{
    for(uint8_t i=0; i<NUM_SENSOR_VALUES; i++)
    {
        pav.sum_rgbc[i] += pav.rgbc[i];
    }
    pav.sumCount++;
}

inline void clearRGBSum()
{
    pav.sumCount = 0;
    for(uint8_t i=0; i<NUM_SENSOR_VALUES; i++)
    {
        pav.sum_rgbc[i] = 0;
    }
}

void loop()
{

    csensor.startIntegration();
    //DO read registers IO expander
//    cycleButtons();
//    cycleLEDs();

    readSerial();
    //fsm_ui.cycle();
    while(!csensor.is_integrated());
    csensor.read_data_rgbc(pav.rgbc);
    //print(param_print_values(rgbc)+"\n");
    addToRGBSum();
    //print(String(pav.sumCount) + param_print_values(pav.sum_rgbc)+"\n");

    //if(pav.sum_rgbc[3] > pav.sumThreshold || pav.sumCount >= pav.sumMaxCount){
    if(pav.sumCount < pav.sumMaxCount)
    {
        return;
    }

    fsm_main.cycle();
    print("~RGBC " + param_print_values(pav.sum_rgbc, NUM_SENSOR_VALUES, F_RGBC)+ "\n");
    clearRGBSum();

    //delay(10);
    //IF sensor reading is done
    //fsm_main.cycle();
    //DO update values in RAM/EEPROM
    //DO write DMX output
    //DO send serial monitor
}

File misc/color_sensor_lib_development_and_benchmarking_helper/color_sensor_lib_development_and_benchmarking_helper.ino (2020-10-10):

#include <Wire.h>
#include "TCS34725.h"

#define TEST_PIN 6

TCS34725 sensor;
uint16_t rgbc[4];
uint16_t sum_rgbc[4];


void param_print_values(uint16_t rgbc[]) {
  char buff[32];
  String str_print;
  for (int i = 0; i < 4; i++) {
    sprintf(buff, ", %05d", rgbc[i]);
    str_print += buff;
  }
  Serial.println(str_print);
}

int64_t extract_int(String str) {
  String numString;
  bool inStartsWith = true;
  for (uint8_t i = 0; i < str.length(); i++) {
    char numChar = str.charAt(i);
    if (inStartsWith) {
      if (isDigit(numChar)) {
        inStartsWith = false;
      } else {
        continue;
      }
    }
    if (isDigit(numChar)) {
      numString += numChar;
      continue;
    }
    break;
  }
  return numString.toInt();
}

void setup() {
  pinMode(TEST_PIN, OUTPUT);
  digitalWrite(TEST_PIN, HIGH);
  Wire.setClock(400000);
  pinMode(LED_BUILTIN, OUTPUT);
  Serial.begin( 115200 );
  sensor = TCS34725();
  if (sensor.begin()) {
    Serial.println("Found sensor");
  } else {
    Serial.println("No TCS34725 found ... check your connections");
  }
  sensor.adjust_background_clear();
  sensor.setIntegrationTime(2.4);
  sensor.setIntegrationTime(4.8);
  sensor.setIntegrationTime(7.2);
  sensor.setIntegrationTime(9.6);
  sensor.setIntegrationTime(12);
  sensor.setIntegrationTime(24);
  sensor.setIntegrationTime(4.8);
  sensor.setGain(TCS34725_GAIN_1X);
}

int i = 15;
unsigned long t_start = 0;
bool old_mode = false;
bool check_valid = false;

void loop() {
  if(Serial.available()){
    String str = Serial.readString();
    if (str=="o\n"){
      old_mode = true;
    }else if (str=="n\n"){
      old_mode = false;
    }else{
      int64_t x = extract_int(str);
      sensor.setIntegrationTime(2.4*x);
    }
  }
  //digitalWrite(TEST_PIN, LOW);
  sensor.startIntegration();  
  while(!sensor.is_integrated())
  if(old_mode==false){
    digitalWrite(TEST_PIN, HIGH);
    sensor.read_data_rgbc(rgbc);
  }else{
    digitalWrite(TEST_PIN, HIGH);
    sensor.read_data_rgbc_old(rgbc);
  }
  digitalWrite(TEST_PIN, LOW);
  param_print_values(rgbc);
  //digitalWrite(TEST_PIN, HIGH);
}

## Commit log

2020-07-09 fixturematch works for parametrizing with fsm
    [TCS34725.h, fsm.cpp, main.cpp]
2020-07-09 added script for parametrize, bugfixes
    [fsm.cpp, main.cpp, parametize_tty.py]
2020-07-13 coloralgorithm in python working
    [adj_megatripar_all.csv, adj_megatripar_blue.csv, adj_megatripar_green.csv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]
2020-07-24 added buttons for ref and match, autoformated code
2020-08-04 initial kicad commit, with basic circuits
    [board.kicad_pcb, board.sch]
2020-08-09 sch and pcb for main board designed
    [board.kicad_pcb, board.sch]
2020-08-21 extended, improved and finished circuits and boards
    also added PDF and renders of shematic/board
    INFO: The Displays Library is not included and can be found at
    https://github.com/jonolt/KiCad_lib_EA-Dispaly
    [FileDisplays.sch, board.kicad_pcb, board.sch]
2020-08-21 renamed KiCad project directories to board names
    [FileDisplays.sch, board.kicad_pcb, board.sch]
2020-08-23 added values and manufacurer id (kicost), improvements
    BOTH
    - added missing values for resitors and diodes
    - added manf# for calculating and ordering with kicost
    - minor improvements
    NanoE-dmx
    - bus controll LEDs (buffered) fixed for TX/RX, SDA/SCL
    - changed J40 (RJ45(8pol)->Conn(4pol)
    - added ISO 5V LED
    UI-Shield
    - Replaced U2 (MAX5026->LM2705), for higher max current
    - added 2 leds at NC IO ports
    [FileDisplays.sch, board.kicad_pcb, board.sch]
2020-08-27 minor cleanup
    [board.kicad_pcb, board.sch]
2020-09-07 basics of DMX, Sensor and Serial works
2020-10-10 implemented basic python gui and serial communication
    [command_list.ods]
